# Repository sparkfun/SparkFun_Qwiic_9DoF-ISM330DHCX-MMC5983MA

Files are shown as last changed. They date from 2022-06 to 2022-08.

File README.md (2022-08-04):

SparkFun Qwiic 9DoF ISM330DHCX, MMC5983MA
========================================

SparkFun_Qwiic_9DoF-ISM330DHCX-MMC5983MA (https://www.sparkfun.com/products/19895)

[*SparkFun_Qwiic_9DoF-ISM330DHCX-MMC5983MA (19895)*](https://www.sparkfun.com/products/19895)

The SparkFun 9DoF IMU Breakout - ISM330DHCX, MMC5983MA (Qwiic) combines the high-performance ISM330DHCX 3D digital accelerometer and gyroscope from STMicroelectronics with the highly sensitive triple-axis magnetometer by MEMSIC to give you an ultra powerful, easy to use, Qwiic enabled breakout board. 

With a full scale acceleration range of ±2/±4/±8/±16 g and a wide angular rate range of ±125/±250/±500/±1000/±2000/±4000 dps, as well as an unmatched set of embedded features (Machine Learning Core, programmable FSM, FIFO, sensor hub, event decoding and interrupts), the ISM330DHCX delivers high performance at very low power. Add to that the MMC5983MA, which can measure magnetic fields within the full scale range of &#177;8 Gauss (G), with 0.25mG/0.0625mG per LSB resolution at 16bits/18bits operation mode and 0.4 mG total RMS noise level and you've got 9 Degrees of Freedom on one tiny little breakout board. 

Utilizing our handy Qwiic system, no soldering is required to connect it to the rest of your system. However, we still have broken out 0.1"-spaced pins in case you prefer to use a breadboard.  
  
Repository Contents
-------------------

* **/Documentation** - Data sheets, additional product information
* **/Hardware** - Eagle design files (.brd, .sch)
* **/Production** - Production panel files (.brd)

Documentation
--------------

* **[6DoF ISM330DHCX Library](https://github.com/sparkfun/SparkFun_6DoF_ISM330DHCX_Arduino_Library)** - Arduino library for the SparkFun Qwiic 6DoF ISM330DHCX.
* **[MMC5983MA Magnetometer Library](https://github.com/sparkfun/SparkFun_MMC5983MA_Magnetometer_Arduino_Library)** - Arduino library for the SparkFun Qwiic MMC5983MA Magnetometer.
* **[Hookup Guide](https://learn.sparkfun.com/tutorials/2616)** - Basic hookup guide for the SparkFun Qwiic 9DoF-ISM330DHCX-MMC5983MA.

License Information
-------------------

This product is _**open source**_! 

Please review the LICENSE.md file for license information. 

If you have any questions or concerns on licensing, please contact technical support on our [SparkFun forums](https://forum.sparkfun.com/viewforum.php?f=152).

Distributed as-is; no warranty is given.

- Your friends at SparkFun.

_<COLLABORATION CREDIT>_

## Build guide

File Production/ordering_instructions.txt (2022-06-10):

panel size, 169x117mm
PCB thickness, 1.6mm
number of layers, 2
soldermask color, Red
silkscreen color, White
oz copper, 1oz
finish, HASL lead free
stencils, top
pcs per panel, 24
min trace width, 0.2032mm / 0.0080in
min drill size, 0.3048mm / 0.0120in

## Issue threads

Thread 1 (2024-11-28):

Yaw pitch roll

ujwalsahu123, 2024-11-28:
Can you please give code for getting - yaw pitch roll .
Also can you explain or give steps how to get accurate RPY values . (Like - caliberation , sensor fusion , ...etc )

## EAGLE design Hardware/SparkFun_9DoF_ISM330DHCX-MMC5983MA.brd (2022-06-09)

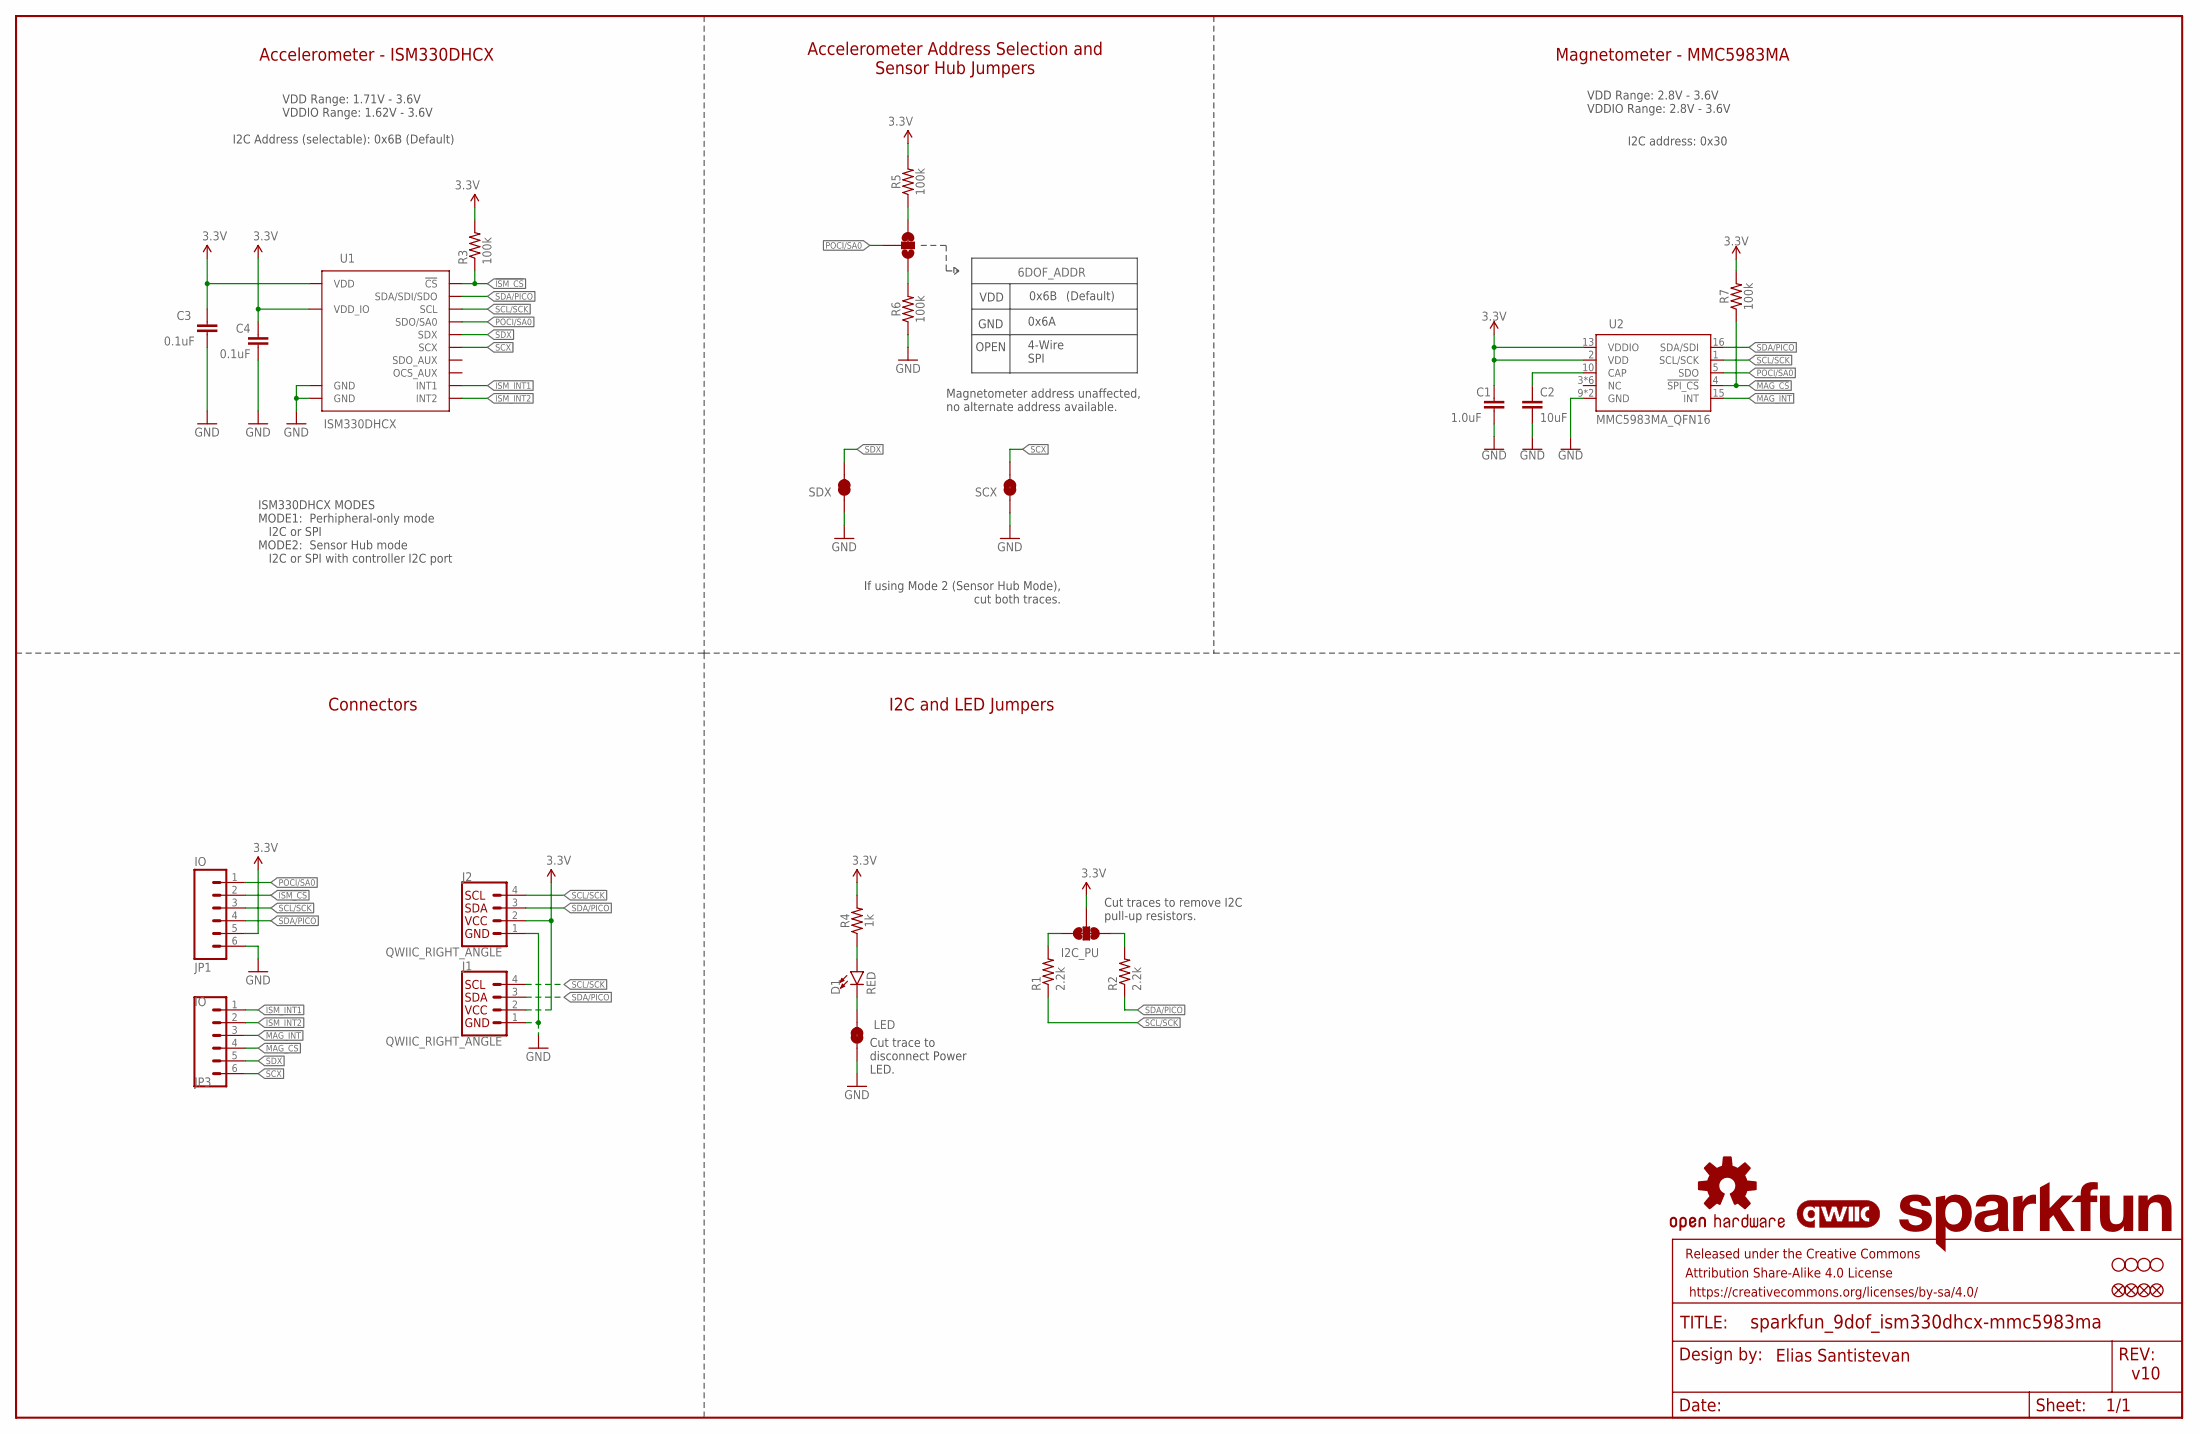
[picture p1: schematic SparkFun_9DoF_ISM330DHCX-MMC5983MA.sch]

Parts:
6DOF_ADDR: JUMPER-SMT_3_1-NC_TRACE_SILK; SMT-JUMPER_3_1-NC_TRACE_SILK
C1: 1.0uF; 0603
C2: 10uF; 0603
C3, C4: 0.1uF; 0603
D1: RED; LED-0603
FD1, FD2: FIDUCIALUFIDUCIAL; FIDUCIAL-MICRO
FID1, FID2: FIDUCIALUFIDUCIAL; FIDUCIAL-MICRO
FRAME2: FRAME-LEDGER; CREATIVE_COMMONS
I2C_PU: S_MODE; SMT-JUMPER_3_2-NC_TRACE_SILK
J1, J2: QWIIC_RIGHT_ANGLE; JST04_1MM_RA
JP1, JP3: IO; 1X06_NO_SILK
LED: JUMPER-SMT_2_NC_TRACE_SILK; SMT-JUMPER_2_NC_TRACE_SILK
LOGO1: QWIIC_LOGO_4MM; QWIIC_4MM
LOGO2: OSHW-LOGOMINI; OSHW-LOGO-MINI
LOGO3: SFE_LOGO_NAME.1_INCH; SFE_LOGO_NAME_.1
R1, R2: 2.2k; 0603
R3, R5, R6, R7: 100k; 0603
R4: 1k; 0603
SCX: JUMPER-SMT_2_NC_TRACE_SILK; SMT-JUMPER_2_NC_TRACE_SILK
SDX: JUMPER-SMT_2_NC_TRACE_SILK; SMT-JUMPER_2_NC_TRACE_SILK
STANDOFF1, STANDOFF2, STANDOFF3, STANDOFF4: STAND-OFFTIGHT; STAND-OFF-TIGHT
U1: ISM330DHCX; LGA-14L
U2: MMC5983MA_QFN16; LGA-16-3X3MM-4X4PINS

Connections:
3.3V: C1.1, C3.1, C4.1, I2C_PU.2, J1.2, J2.2, JP1.5, R3.2, R4.2, R5.2, R7.2, U1.P5 (VDD_IO), U1.P8 (VDD), U2.2 (VDD), U2.13 (VDDIO)
!ISM_CS!: JP1.2, R3.1, U1.P12 (!CS!)
!MAG_CS!: JP3.4, R7.1, U2.4 (!SPI_CS!)
CAP: C2.1, U2.10 (CAP)
GND: C1.2, C2.2, C3.2, C4.2, J1.1, J2.1, JP1.6, LED.1, R6.1, SCX.1, SDX.1, U1.P6 (GND), U1.P7 (GND), U2.9 (GND), U2.11 (GND)
ISM_INT1: JP3.1, U1.P4 (INT1)
ISM_INT2: JP3.2, U1.P9 (INT2)
MAG_INT: JP3.3, U2.15 (INT)
unnamed: 6DOF_ADDR.3, R5.1
unnamed: D1.A, R4.1
unnamed: D1.C, LED.2
unnamed: I2C_PU.1, R1.2
unnamed: I2C_PU.3, R2.2
unnamed: 6DOF_ADDR.1, R6.2
POCI/SA0: 6DOF_ADDR.2, JP1.1, U1.P1 (SDO/SA0), U2.5 (SDO)
SCL/SCK: J1.4, J2.4, JP1.3, R1.1, U1.P13 (SCL), U2.1 (SCL/SCK)
SCX: JP3.6, SCX.2, U1.P3 (SCX)
SDA/PICO: J1.3, J2.3, JP1.4, R2.1, U1.P14 (SDA/SDI/SDO), U2.16 (SDA/SDI)
SDX: JP3.5, SDX.2, U1.P2 (SDX)

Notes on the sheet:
Accelerometer - ISM330DHCX
Cut traces to remove I2C pull-up resistors.
VDD Range: 1.71V - 3.6V VDDIO Range: 1.62V - 3.6V
v10
Cut trace to disconnect Power LED.
Connectors
VDD
GND
OPEN
0x6B
0x6A
4-Wire SPI
Elias Santistevan
VDD Range: 2.8V - 3.6V VDDIO Range: 2.8V - 3.6V
Magnetometer - MMC5983MA
Accelerometer Address Selection and Sensor Hub Jumpers
I2C and LED Jumpers
I2C address: 0x30
(Default)
I2C Address (selectable): 0x6B (Default)
ISM330DHCX MODES MODE1: Perhipheral-only mode I2C or SPI MODE2: Sensor Hub mode I2C or SPI with controller I2C port
If using Mode 2 (Sensor Hub Mode), cut both traces.
Magnetometer address unaffected, no alternate address available.

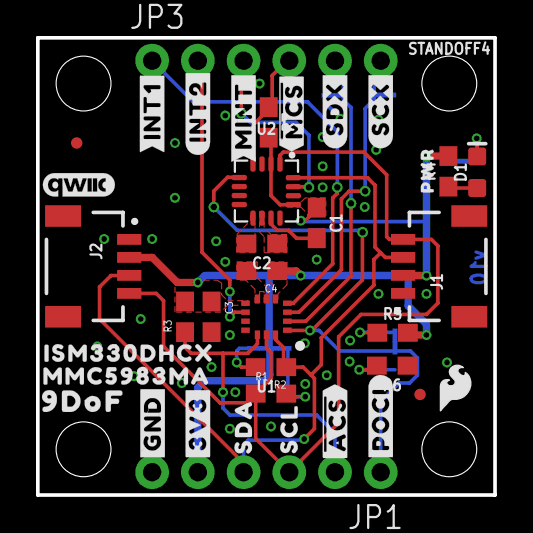
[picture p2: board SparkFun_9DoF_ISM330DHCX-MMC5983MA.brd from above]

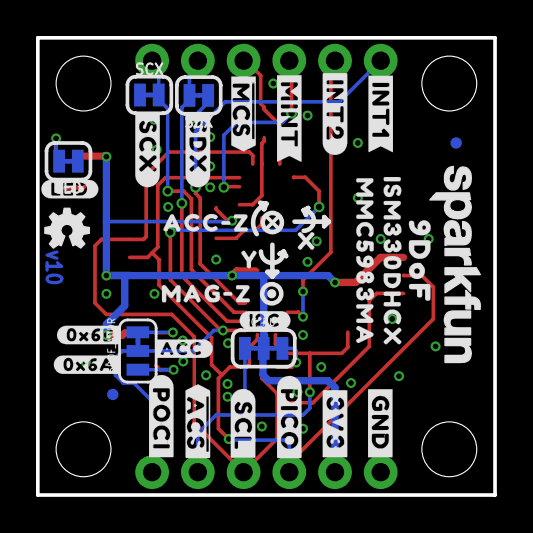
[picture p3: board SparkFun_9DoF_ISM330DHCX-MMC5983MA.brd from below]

Board: 2 copper layers, 25.4 x 25.4 mm, 76 parts (33 on the bottom side), 19 nets.

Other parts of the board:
U$1, U$15: #3V3#1
U$2, U$17: #GND#0
U$3, U$7: ISM330DHCX331
U$4: SDA14
U$5: SCL13
U$6: #POCI#11
U$8: #INT1#0
U$9: #INT2#3
U$10: #INT1#2
U$11: #INT2#2
U$12: #MINT#4
U$13: ACC#Z5985
U$14: MAG#Z5984
U$16: #LED#11
U$18: #POCI#12
U$19: ##MCS##5
U$20: #SDX#7
U$21, U$32: MMC5983MA24
U$22: #SCL#5
U$23: #SCX#8
U$24, U$30: 9DOF24
U$25: #I2C#11
U$26: #PICO#13
U$27: ##ACS##6
U$28: PWR8
U$29: SFE_LOGO_FLAME_.1
U$31: #MINT#5
U$33: #0X6A#15
U$34: ##MCS##7
U$35: #SDX#9
U$36: #SCX#11
U$37: X2114
U$38: Y2115
U$39: ##ACS##8
U$40: #0X6B#15
U$41: #ACC#17

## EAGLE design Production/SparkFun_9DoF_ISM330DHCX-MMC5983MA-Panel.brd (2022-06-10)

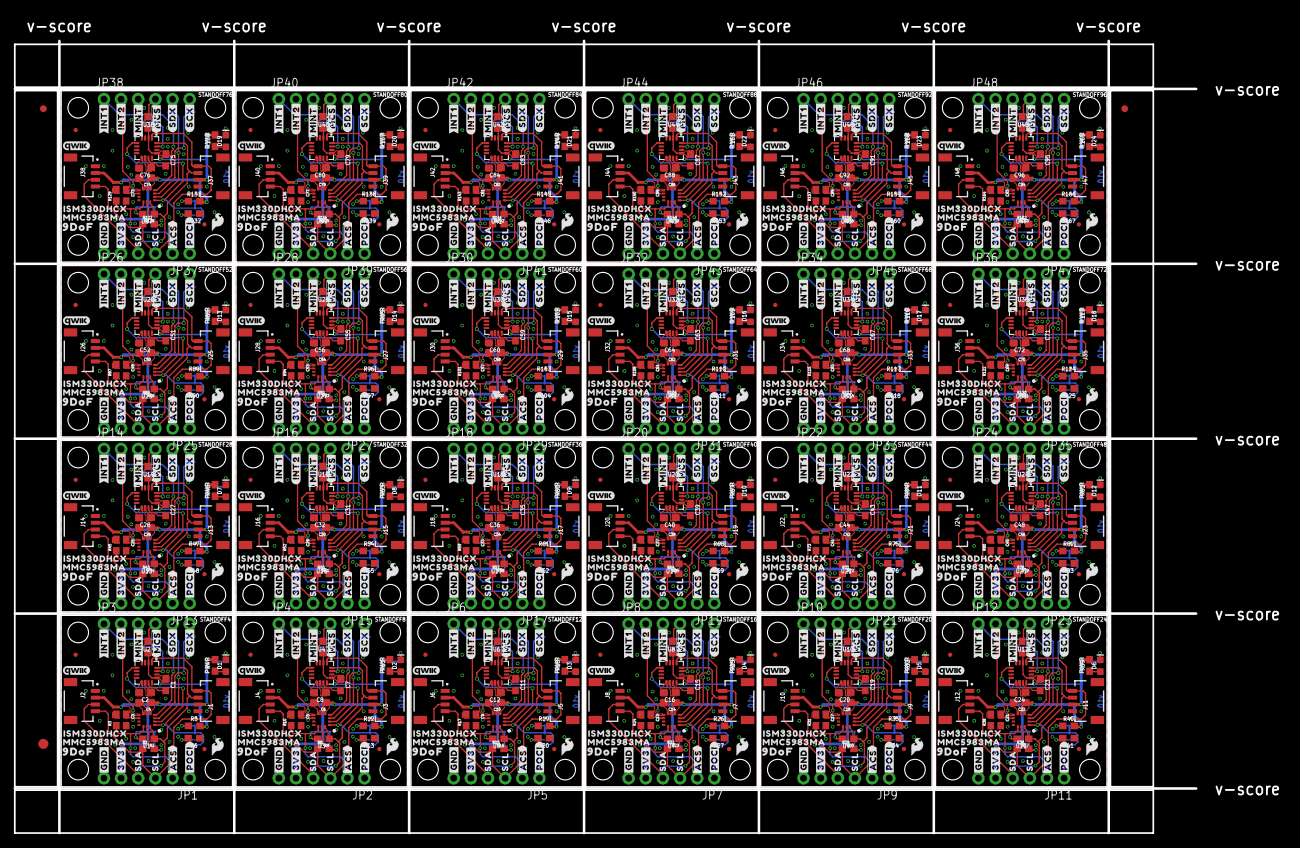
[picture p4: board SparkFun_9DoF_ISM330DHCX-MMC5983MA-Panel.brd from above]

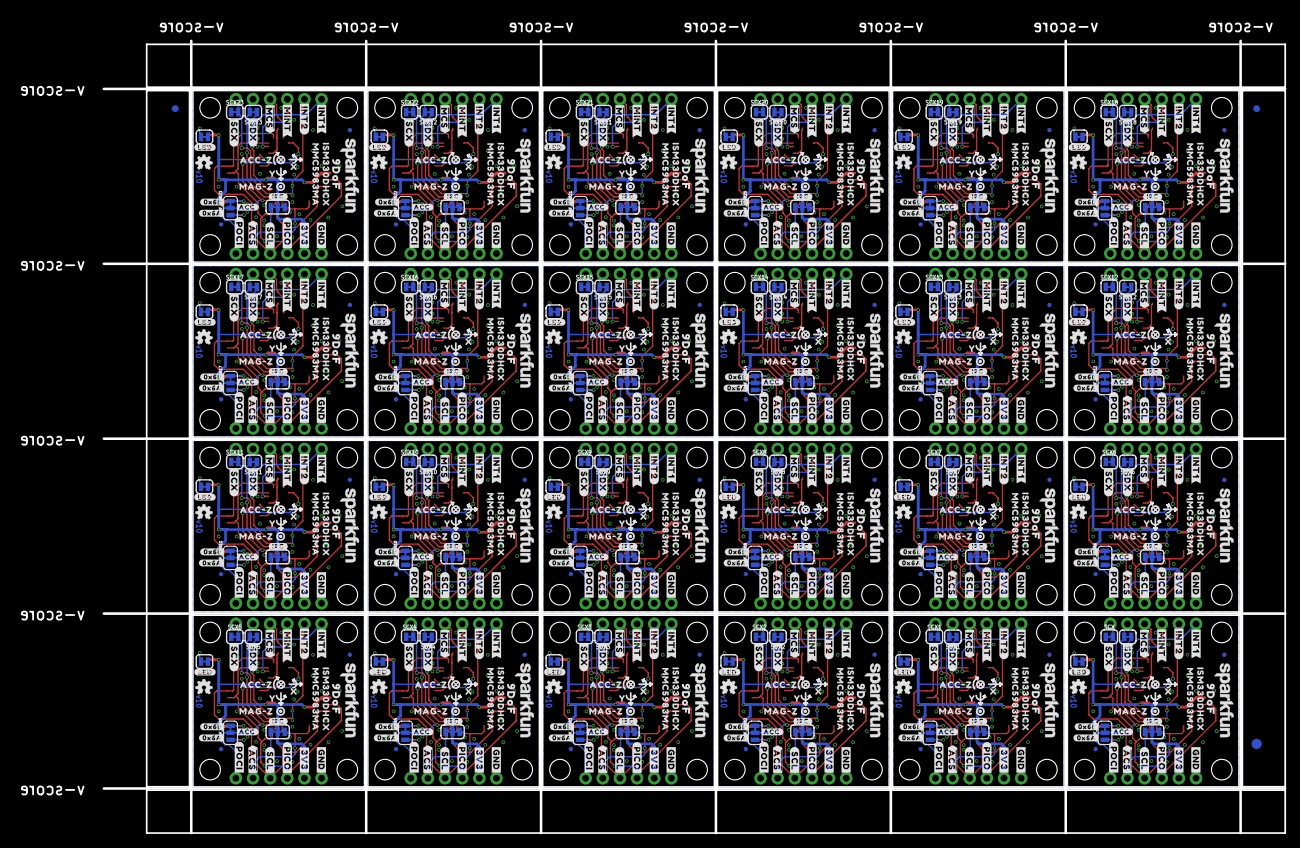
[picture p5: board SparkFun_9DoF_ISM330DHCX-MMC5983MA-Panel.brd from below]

Board: 2 copper layers, 175.0 x 117.3 mm, 1806 parts (795 on the bottom side), 456 nets.

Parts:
6DOF_ADDR, 6DOF_ADDR1, 6DOF_ADDR2, 6DOF_ADDR3, 6DOF_ADDR4, 6DOF_ADDR5, 6DOF_ADDR6, 6DOF_ADDR7, 6DOF_ADDR8, 6DOF_ADDR9, 6DOF_ADDR10, 6DOF_ADDR11, 6DOF_ADDR12, 6DOF_ADDR13, 6DOF_ADDR14, 6DOF_ADDR15, 6DOF_ADDR16, 6DOF_ADDR17, 6DOF_ADDR18, 6DOF_ADDR19, 6DOF_ADDR20, 6DOF_ADDR21, 6DOF_ADDR22, 6DOF_ADDR23: JUMPER-SMT_3_1-NC_TRACE_SILK; SMT-JUMPER_3_1-NC_TRACE_SILK
C1, C7, C11, C15, C19, C23, C27, C31, C35, C39, C43, C47, C51, C55, C59, C63, C67, C71, C75, C79, C83, C87, C91, C95: 1.0uF; 0603
C2, C8, C12, C16, C20, C24, C28, C32, C36, C40, C44, C48, C52, C56, C60, C64, C68, C72, C76, C80, C84, C88, C92, C96: 10uF; 0603
C3, C4, C5, C6, C9, C10, C13, C14, C17, C18, C21, C22, C25, C26, C29, C30, C33, C34, C37, C38, C41, C42, C45, C46, C49, C50, C53, C54, C57, C58, C61, C62, C65, C66, C69, C70, C73, C74, C77, C78, C81, C82, C85, C86, C89, C90, C93, C94: 0.1uF; 0603
D1, D2, D3, D4, D5, D6, D7, D8, D9, D10, D11, D12, D13, D14, D15, D16, D17, D18, D19, D20, D21, D22, D23, D24: RED; LED-0603
E$1, E$2, E$3, E$4: FIDUCIAL-1X2
E$5, E$6: FIDUCIAL-1.5X3
FD1, FD2, FD3, FD4, FD5, FD6, FD7, FD8, FD9, FD10, FD11, FD12, FD13, FD14, FD15, FD16, FD17, FD18, FD19, FD20, FD21, FD22, FD23, FD24, FD25, FD26, FD27, FD28, FD29, FD30, FD31, FD32, FD33, FD34, FD35, FD36, FD37, FD38, FD39, FD40, FD41, FD42, FD43, FD44, FD45, FD46, FD47, FD48: FIDUCIALUFIDUCIAL; FIDUCIAL-MICRO
FID1, FID2, FID3, FID4, FID5, FID6, FID7, FID8, FID9, FID10, FID11, FID12, FID13, FID14, FID15, FID16, FID17, FID18, FID19, FID20, FID21, FID22, FID23, FID24, FID25, FID26, FID27, FID28, FID29, FID30, FID31, FID32, FID33, FID34, FID35, FID36, FID37, FID38, FID39, FID40, FID41, FID42, FID43, FID44, FID45, FID46, FID47, FID48: FIDUCIALUFIDUCIAL; FIDUCIAL-MICRO
I2C_PU, I2C_PU1, I2C_PU2, I2C_PU3, I2C_PU4, I2C_PU5, I2C_PU6, I2C_PU7, I2C_PU8, I2C_PU9, I2C_PU10, I2C_PU11, I2C_PU12, I2C_PU13, I2C_PU14, I2C_PU15, I2C_PU16, I2C_PU17, I2C_PU18, I2C_PU19, I2C_PU20, I2C_PU21, I2C_PU22, I2C_PU23: S_MODE; SMT-JUMPER_3_2-NC_TRACE_SILK
J1, J2, J3, J4, J5, J6, J7, J8, J9, J10, J11, J12, J13, J14, J15, J16, J17, J18, J19, J20, J21, J22, J23, J24, J25, J26, J27, J28, J29, J30, J31, J32, J33, J34, J35, J36, J37, J38, J39, J40, J41, J42, J43, J44, J45, J46, J47, J48: QWIIC_RIGHT_ANGLE; JST04_1MM_RA
JP1, JP2, JP3, JP4, JP5, JP6, JP7, JP8, JP9, JP10, JP11, JP12, JP13, JP14, JP15, JP16, JP17, JP18, JP19, JP20, JP21, JP22, JP23, JP24, JP25, JP26, JP27, JP28, JP29, JP30, JP31, JP32, JP33, JP34, JP35, JP36, JP37, JP38, JP39, JP40, JP41, JP42, JP43, JP44, JP45, JP46, JP47, JP48: IO; 1X06_NO_SILK
LED, LED1, LED2, LED3, LED4, LED5, LED6, LED7, LED8, LED9, LED10, LED11, LED12, LED13, LED14, LED15, LED16, LED17, LED18, LED19, LED20, LED21, LED22, LED23: JUMPER-SMT_2_NC_TRACE_SILK; SMT-JUMPER_2_NC_TRACE_SILK
LOGO1, LOGO6, LOGO9, LOGO12, LOGO15, LOGO18, LOGO21, LOGO24, LOGO27, LOGO30, LOGO33, LOGO36, LOGO39, LOGO42, LOGO45, LOGO48, LOGO51, LOGO54, LOGO57, LOGO60, LOGO63, LOGO66, LOGO69, LOGO72: QWIIC_LOGO_4MM; QWIIC_4MM
LOGO2, LOGO4, LOGO7, LOGO10, LOGO13, LOGO16, LOGO19, LOGO22, LOGO25, LOGO28, LOGO31, LOGO34, LOGO37, LOGO40, LOGO43, LOGO46, LOGO49, LOGO52, LOGO55, LOGO58, LOGO61, LOGO64, LOGO67, LOGO70: OSHW-LOGOMINI; OSHW-LOGO-MINI
LOGO3, LOGO5, LOGO8, LOGO11, LOGO14, LOGO17, LOGO20, LOGO23, LOGO26, LOGO29, LOGO32, LOGO35, LOGO38, LOGO41, LOGO44, LOGO47, LOGO50, LOGO53, LOGO56, LOGO59, LOGO62, LOGO65, LOGO68, LOGO71: SFE_LOGO_NAME.1_INCH; SFE_LOGO_NAME_.1
R1, R2, R8, R9, R15, R16, R22, R23, R29, R30, R36, R37, R43, R44, R50, R51, R57, R58, R64, R65, R71, R72, R78, R79, R85, R86, R92, R93, R99, R100, R106, R107, R113, R114, R120, R121, R127, R128, R134, R135, R141, R142, R148, R149, R155, R156, R162, R163: 2.2k; 0603
R3, R5, R6, R7, R10, R12, R13, R14, R17, R19, R20, R21, R24, R26, R27, R28, R31, R33, R34, R35, R38, R40, R41, R42, R45, R47, R48, R49, R52, R54, R55, R56, R59, R61, R62, R63, R66, R68, R69, R70, R73, R75, R76, R77, R80, R82, R83, R84, R87, R89, R90, R91, R94, R96, R97, R98, R101, R103, R104, R105, R108, R110, R111, R112, R115, R117, R118, R119, R122, R124, R125, R126, R129, R131, R132, R133, R136, R138, R139, R140, R143, R145, R146, R147, R150, R152, R153, R154, R157, R159, R160, R161, R164, R166, R167, R168: 100k; 0603
R4, R11, R18, R25, R32, R39, R46, R53, R60, R67, R74, R81, R88, R95, R102, R109, R116, R123, R130, R137, R144, R151, R158, R165: 1k; 0603
SCX, SCX1, SCX2, SCX3, SCX4, SCX5, SCX6, SCX7, SCX8, SCX9, SCX10, SCX11, SCX12, SCX13, SCX14, SCX15, SCX16, SCX17, SCX18, SCX19, SCX20, SCX21, SCX22, SCX23: JUMPER-SMT_2_NC_TRACE_SILK; SMT-JUMPER_2_NC_TRACE_SILK
SDX, SDX1, SDX2, SDX3, SDX4, SDX5, SDX6, SDX7, SDX8, SDX9, SDX10, SDX11, SDX12, SDX13, SDX14, SDX15, SDX16, SDX17, SDX18, SDX19, SDX20, SDX21, SDX22, SDX23: JUMPER-SMT_2_NC_TRACE_SILK; SMT-JUMPER_2_NC_TRACE_SILK
STANDOFF1, STANDOFF2, STANDOFF3, STANDOFF4, STANDOFF5, STANDOFF6, STANDOFF7, STANDOFF8, STANDOFF9, STANDOFF10, STANDOFF11, STANDOFF12, STANDOFF13, STANDOFF14, STANDOFF15, STANDOFF16, STANDOFF17, STANDOFF18, STANDOFF19, STANDOFF20, STANDOFF21, STANDOFF22, STANDOFF23, STANDOFF24, STANDOFF25, STANDOFF26, STANDOFF27, STANDOFF28, STANDOFF29, STANDOFF30, STANDOFF31, STANDOFF32, STANDOFF33, STANDOFF34, STANDOFF35, STANDOFF36, STANDOFF37, STANDOFF38, STANDOFF39, STANDOFF40, STANDOFF41, STANDOFF42, STANDOFF43, STANDOFF44, STANDOFF45, STANDOFF46, STANDOFF47, STANDOFF48, STANDOFF49, STANDOFF50, STANDOFF51, STANDOFF52, STANDOFF53, STANDOFF54, STANDOFF55, STANDOFF56, STANDOFF57, STANDOFF58, STANDOFF59, STANDOFF60, STANDOFF61, STANDOFF62, STANDOFF63, STANDOFF64, STANDOFF65, STANDOFF66, STANDOFF67, STANDOFF68, STANDOFF69, STANDOFF70, STANDOFF71, STANDOFF72, STANDOFF73, STANDOFF74, STANDOFF75, STANDOFF76, STANDOFF77, STANDOFF78, STANDOFF79, STANDOFF80, STANDOFF81, STANDOFF82, STANDOFF83, STANDOFF84, STANDOFF85, STANDOFF86, STANDOFF87, STANDOFF88, STANDOFF89, STANDOFF90, STANDOFF91, STANDOFF92, STANDOFF93, STANDOFF94, STANDOFF95, STANDOFF96: STAND-OFFTIGHT; STAND-OFF-TIGHT
U1, U3, U5, U7, U9, U11, U13, U15, U17, U19, U21, U23, U25, U27, U29, U31, U33, U35, U37, U39, U41, U43, U45, U47: ISM330DHCX; LGA-14L
U2, U4, U6, U8, U10, U12, U14, U16, U18, U20, U22, U24, U26, U28, U30, U32, U34, U36, U38, U40, U42, U44, U46, U48: MMC5983MA_QFN16; LGA-16-3X3MM-4X4PINS
U$1, U$15, U$42, U$44, U$83, U$85, U$124, U$126, U$165, U$167, U$206, U$208, U$247, U$249, U$288, U$290, U$329, U$331, U$370, U$372, U$411, U$413, U$452, U$454, U$493, U$495, U$534, U$536, U$575, U$577, U$616, U$618, U$657, U$659, U$698, U$700, U$739, U$741, U$780, U$782, U$821, U$823, U$862, U$864, U$903, U$905, U$944, U$946: #3V3#1
U$2, U$17, U$43, U$45, U$84, U$86, U$125, U$127, U$166, U$168, U$207, U$209, U$248, U$250, U$289, U$291, U$330, U$332, U$371, U$373, U$412, U$414, U$453, U$455, U$494, U$496, U$535, U$537, U$576, U$578, U$617, U$619, U$658, U$660, U$699, U$701, U$740, U$742, U$781, U$783, U$822, U$824, U$863, U$865, U$904, U$906, U$945, U$947: #GND#0
U$3, U$7, U$64, U$65, U$105, U$106, U$146, U$147, U$187, U$188, U$228, U$229, U$269, U$270, U$310, U$311, U$351, U$352, U$392, U$393, U$433, U$434, U$474, U$475, U$515, U$516, U$556, U$557, U$597, U$598, U$638, U$639, U$679, U$680, U$720, U$721, U$761, U$762, U$802, U$803, U$843, U$844, U$884, U$885, U$925, U$926, U$966, U$967: ISM330DHCX331
U$4, U$78, U$119, U$160, U$201, U$242, U$283, U$324, U$365, U$406, U$447, U$488, U$529, U$570, U$611, U$652, U$693, U$734, U$775, U$816, U$857, U$898, U$939, U$980: SDA14
U$5, U$79, U$120, U$161, U$202, U$243, U$284, U$325, U$366, U$407, U$448, U$489, U$530, U$571, U$612, U$653, U$694, U$735, U$776, U$817, U$858, U$899, U$940, U$981: SCL13
U$6, U$52, U$93, U$134, U$175, U$216, U$257, U$298, U$339, U$380, U$421, U$462, U$503, U$544, U$585, U$626, U$667, U$708, U$749, U$790, U$831, U$872, U$913, U$954: #POCI#11
U$8, U$66, U$107, U$148, U$189, U$230, U$271, U$312, U$353, U$394, U$435, U$476, U$517, U$558, U$599, U$640, U$681, U$722, U$763, U$804, U$845, U$886, U$927, U$968: #INT1#0
U$9, U$74, U$115, U$156, U$197, U$238, U$279, U$320, U$361, U$402, U$443, U$484, U$525, U$566, U$607, U$648, U$689, U$730, U$771, U$812, U$853, U$894, U$935, U$976: #INT2#3
U$10, U$67, U$108, U$149, U$190, U$231, U$272, U$313, U$354, U$395, U$436, U$477, U$518, U$559, U$600, U$641, U$682, U$723, U$764, U$805, U$846, U$887, U$928, U$969: #INT1#2
U$11, U$68, U$109, U$150, U$191, U$232, U$273, U$314, U$355, U$396, U$437, U$478, U$519, U$560, U$601, U$642, U$683, U$724, U$765, U$806, U$847, U$888, U$929, U$970: #INT2#2
U$12, U$69, U$110, U$151, U$192, U$233, U$274, U$315, U$356, U$397, U$438, U$479, U$520, U$561, U$602, U$643, U$684, U$725, U$766, U$807, U$848, U$889, U$930, U$971: #MINT#4
U$13, U$62, U$103, U$144, U$185, U$226, U$267, U$308, U$349, U$390, U$431, U$472, U$513, U$554, U$595, U$636, U$677, U$718, U$759, U$800, U$841, U$882, U$923, U$964: ACC#Z5985
U$14, U$63, U$104, U$145, U$186, U$227, U$268, U$309, U$350, U$391, U$432, U$473, U$514, U$555, U$596, U$637, U$678, U$719, U$760, U$801, U$842, U$883, U$924, U$965: MAG#Z5984
U$16, U$47, U$88, U$129, U$170, U$211, U$252, U$293, U$334, U$375, U$416, U$457, U$498, U$539, U$580, U$621, U$662, U$703, U$744, U$785, U$826, U$867, U$908, U$949: #LED#11
U$18, U$53, U$94, U$135, U$176, U$217, U$258, U$299, U$340, U$381, U$422, U$463, U$504, U$545, U$586, U$627, U$668, U$709, U$750, U$791, U$832, U$873, U$914, U$955: #POCI#12
U$19, U$70, U$111, U$152, U$193, U$234, U$275, U$316, U$357, U$398, U$439, U$480, U$521, U$562, U$603, U$644, U$685, U$726, U$767, U$808, U$849, U$890, U$931, U$972: ##MCS##5
U$20, U$71, U$112, U$153, U$194, U$235, U$276, U$317, U$358, U$399, U$440, U$481, U$522, U$563, U$604, U$645, U$686, U$727, U$768, U$809, U$850, U$891, U$932, U$973: #SDX#7
U$21, U$32, U$56, U$59, U$97, U$100, U$138, U$141, U$179, U$182, U$220, U$223, U$261, U$264, U$302, U$305, U$343, U$346, U$384, U$387, U$425, U$428, U$466, U$469, U$507, U$510, U$548, U$551, U$589, U$592, U$630, U$633, U$671, U$674, U$712, U$715, U$753, U$756, U$794, U$797, U$835, U$838, U$876, U$879, U$917, U$920, U$958, U$961: MMC5983MA24
U$22, U$46, U$87, U$128, U$169, U$210, U$251, U$292, U$333, U$374, U$415, U$456, U$497, U$538, U$579, U$620, U$661, U$702, U$743, U$784, U$825, U$866, U$907, U$948: #SCL#5
U$23, U$72, U$113, U$154, U$195, U$236, U$277, U$318, U$359, U$400, U$441, U$482, U$523, U$564, U$605, U$646, U$687, U$728, U$769, U$810, U$851, U$892, U$933, U$974: #SCX#8
U$24, U$30, U$57, U$58, U$98, U$99, U$139, U$140, U$180, U$181, U$221, U$222, U$262, U$263, U$303, U$304, U$344, U$345, U$385, U$386, U$426, U$427, U$467, U$468, U$508, U$509, U$549, U$550, U$590, U$591, U$631, U$632, U$672, U$673, U$713, U$714, U$754, U$755, U$795, U$796, U$836, U$837, U$877, U$878, U$918, U$919, U$959, U$960: 9DOF24
U$25, U$48, U$89, U$130, U$171, U$212, U$253, U$294, U$335, U$376, U$417, U$458, U$499, U$540, U$581, U$622, U$663, U$704, U$745, U$786, U$827, U$868, U$909, U$950: #I2C#11
U$26, U$51, U$92, U$133, U$174, U$215, U$256, U$297, U$338, U$379, U$420, U$461, U$502, U$543, U$584, U$625, U$666, U$707, U$748, U$789, U$830, U$871, U$912, U$953: #PICO#13
U$27, U$73, U$114, U$155, U$196, U$237, U$278, U$319, U$360, U$401, U$442, U$483, U$524, U$565, U$606, U$647, U$688, U$729, U$770, U$811, U$852, U$893, U$934, U$975: ##ACS##6
U$28, U$49, U$90, U$131, U$172, U$213, U$254, U$295, U$336, U$377, U$418, U$459, U$500, U$541, U$582, U$623, U$664, U$705, U$746, U$787, U$828, U$869, U$910, U$951: PWR8
U$29, U$50, U$91, U$132, U$173, U$214, U$255, U$296, U$337, U$378, U$419, U$460, U$501, U$542, U$583, U$624, U$665, U$706, U$747, U$788, U$829, U$870, U$911, U$952: SFE_LOGO_FLAME_.1
U$31, U$80, U$121, U$162, U$203, U$244, U$285, U$326, U$367, U$408, U$449, U$490, U$531, U$572, U$613, U$654, U$695, U$736, U$777, U$818, U$859, U$900, U$941, U$982: #MINT#5
U$33, U$60, U$101, U$142, U$183, U$224, U$265, U$306, U$347, U$388, U$429, U$470, U$511, U$552, U$593, U$634, U$675, U$716, U$757, U$798, U$839, U$880, U$921, U$962: #0X6A#15
U$34, U$81, U$122, U$163, U$204, U$245, U$286, U$327, U$368, U$409, U$450, U$491, U$532, U$573, U$614, U$655, U$696, U$737, U$778, U$819, U$860, U$901, U$942, U$983: ##MCS##7
U$35, U$75, U$116, U$157, U$198, U$239, U$280, U$321, U$362, U$403, U$444, U$485, U$526, U$567, U$608, U$649, U$690, U$731, U$772, U$813, U$854, U$895, U$936, U$977: #SDX#9
U$36, U$76, U$117, U$158, U$199, U$240, U$281, U$322, U$363, U$404, U$445, U$486, U$527, U$568, U$609, U$650, U$691, U$732, U$773, U$814, U$855, U$896, U$937, U$978: #SCX#11
U$37, U$54, U$95, U$136, U$177, U$218, U$259, U$300, U$341, U$382, U$423, U$464, U$505, U$546, U$587, U$628, U$669, U$710, U$751, U$792, U$833, U$874, U$915, U$956: X2114
U$38, U$55, U$96, U$137, U$178, U$219, U$260, U$301, U$342, U$383, U$424, U$465, U$506, U$547, U$588, U$629, U$670, U$711, U$752, U$793, U$834, U$875, U$916, U$957: Y2115
U$39, U$77, U$118, U$159, U$200, U$241, U$282, U$323, U$364, U$405, U$446, U$487, U$528, U$569, U$610, U$651, U$692, U$733, U$774, U$815, U$856, U$897, U$938, U$979: ##ACS##8
U$40, U$61, U$102, U$143, U$184, U$225, U$266, U$307, U$348, U$389, U$430, U$471, U$512, U$553, U$594, U$635, U$676, U$717, U$758, U$799, U$840, U$881, U$922, U$963: #0X6B#15
U$41, U$82, U$123, U$164, U$205, U$246, U$287, U$328, U$369, U$410, U$451, U$492, U$533, U$574, U$615, U$656, U$697, U$738, U$779, U$820, U$861, U$902, U$943, U$984: #ACC#17

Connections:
3.3V: C1.1, C3.1, C4.1, I2C_PU.2, J1.2, J2.2, JP1.5, R3.2, R4.2, R5.2, R7.2, U1.P5, U1.P8, U2.2, U2.13
3.3V1: C5.1, C6.1, C7.1, I2C_PU1.2, J3.2, J4.2, JP2.5, R10.2, R11.2, R12.2, R14.2, U3.P5, U3.P8, U4.2, U4.13
3.3V2: C9.1, C10.1, C11.1, I2C_PU2.2, J5.2, J6.2, JP5.5, R17.2, R18.2, R19.2, R21.2, U5.P5, U5.P8, U6.2, U6.13
3.3V3: C13.1, C14.1, C15.1, I2C_PU3.2, J7.2, J8.2, JP7.5, R24.2, R25.2, R26.2, R28.2, U7.P5, U7.P8, U8.2, U8.13
3.3V4: C17.1, C18.1, C19.1, I2C_PU4.2, J9.2, J10.2, JP9.5, R31.2, R32.2, R33.2, R35.2, U9.P5, U9.P8, U10.2, U10.13
3.3V5: C21.1, C22.1, C23.1, I2C_PU5.2, J11.2, J12.2, JP11.5, R38.2, R39.2, R40.2, R42.2, U11.P5, U11.P8, U12.2, U12.13
3.3V6: C25.1, C26.1, C27.1, I2C_PU6.2, J13.2, J14.2, JP13.5, R45.2, R46.2, R47.2, R49.2, U13.P5, U13.P8, U14.2, U14.13
3.3V7: C29.1, C30.1, C31.1, I2C_PU7.2, J15.2, J16.2, JP15.5, R52.2, R53.2, R54.2, R56.2, U15.P5, U15.P8, U16.2, U16.13
3.3V8: C33.1, C34.1, C35.1, I2C_PU8.2, J17.2, J18.2, JP17.5, R59.2, R60.2, R61.2, R63.2, U17.P5, U17.P8, U18.2, U18.13
3.3V9: C37.1, C38.1, C39.1, I2C_PU9.2, J19.2, J20.2, JP19.5, R66.2, R67.2, R68.2, R70.2, U19.P5, U19.P8, U20.2, U20.13
3.3V10: C41.1, C42.1, C43.1, I2C_PU10.2, J21.2, J22.2, JP21.5, R73.2, R74.2, R75.2, R77.2, U21.P5, U21.P8, U22.2, U22.13
3.3V11: C45.1, C46.1, C47.1, I2C_PU11.2, J23.2, J24.2, JP23.5, R80.2, R81.2, R82.2, R84.2, U23.P5, U23.P8, U24.2, U24.13
3.3V12: C49.1, C50.1, C51.1, I2C_PU12.2, J25.2, J26.2, JP25.5, R87.2, R88.2, R89.2, R91.2, U25.P5, U25.P8, U26.2, U26.13
3.3V13: C53.1, C54.1, C55.1, I2C_PU13.2, J27.2, J28.2, JP27.5, R94.2, R95.2, R96.2, R98.2, U27.P5, U27.P8, U28.2, U28.13
3.3V14: C57.1, C58.1, C59.1, I2C_PU14.2, J29.2, J30.2, JP29.5, R101.2, R102.2, R103.2, R105.2, U29.P5, U29.P8, U30.2, U30.13
3.3V15: C61.1, C62.1, C63.1, I2C_PU15.2, J31.2, J32.2, JP31.5, R108.2, R109.2, R110.2, R112.2, U31.P5, U31.P8, U32.2, U32.13
3.3V16: C65.1, C66.1, C67.1, I2C_PU16.2, J33.2, J34.2, JP33.5, R115.2, R116.2, R117.2, R119.2, U33.P5, U33.P8, U34.2, U34.13
3.3V17: C69.1, C70.1, C71.1, I2C_PU17.2, J35.2, J36.2, JP35.5, R122.2, R123.2, R124.2, R126.2, U35.P5, U35.P8, U36.2, U36.13
3.3V18: C73.1, C74.1, C75.1, I2C_PU18.2, J37.2, J38.2, JP37.5, R129.2, R130.2, R131.2, R133.2, U37.P5, U37.P8, U38.2, U38.13
3.3V19: C77.1, C78.1, C79.1, I2C_PU19.2, J39.2, J40.2, JP39.5, R136.2, R137.2, R138.2, R140.2, U39.P5, U39.P8, U40.2, U40.13
3.3V20: C81.1, C82.1, C83.1, I2C_PU20.2, J41.2, J42.2, JP41.5, R143.2, R144.2, R145.2, R147.2, U41.P5, U41.P8, U42.2, U42.13
3.3V21: C85.1, C86.1, C87.1, I2C_PU21.2, J43.2, J44.2, JP43.5, R150.2, R151.2, R152.2, R154.2, U43.P5, U43.P8, U44.2, U44.13
3.3V22: C89.1, C90.1, C91.1, I2C_PU22.2, J45.2, J46.2, JP45.5, R157.2, R158.2, R159.2, R161.2, U45.P5, U45.P8, U46.2, U46.13
3.3V23: C93.1, C94.1, C95.1, I2C_PU23.2, J47.2, J48.2, JP47.5, R164.2, R165.2, R166.2, R168.2, U47.P5, U47.P8, U48.2, U48.13
!ISM_CS!: JP1.2, R3.1, U1.P12
!ISM_CS!1: JP2.2, R10.1, U3.P12
!ISM_CS!2: JP5.2, R17.1, U5.P12
!ISM_CS!3: JP7.2, R24.1, U7.P12
!ISM_CS!4: JP9.2, R31.1, U9.P12
!ISM_CS!5: JP11.2, R38.1, U11.P12
!ISM_CS!6: JP13.2, R45.1, U13.P12
!ISM_CS!7: JP15.2, R52.1, U15.P12
!ISM_CS!8: JP17.2, R59.1, U17.P12
!ISM_CS!9: JP19.2, R66.1, U19.P12
!ISM_CS!10: JP21.2, R73.1, U21.P12
!ISM_CS!11: JP23.2, R80.1, U23.P12
!ISM_CS!12: JP25.2, R87.1, U25.P12
!ISM_CS!13: JP27.2, R94.1, U27.P12
!ISM_CS!14: JP29.2, R101.1, U29.P12
!ISM_CS!15: JP31.2, R108.1, U31.P12
!ISM_CS!16: JP33.2, R115.1, U33.P12
!ISM_CS!17: JP35.2, R122.1, U35.P12
!ISM_CS!18: JP37.2, R129.1, U37.P12
!ISM_CS!19: JP39.2, R136.1, U39.P12
!ISM_CS!20: JP41.2, R143.1, U41.P12
!ISM_CS!21: JP43.2, R150.1, U43.P12
!ISM_CS!22: JP45.2, R157.1, U45.P12
!ISM_CS!23: JP47.2, R164.1, U47.P12
!MAG_CS!: JP3.4, R7.1, U2.4
!MAG_CS!1: JP4.4, R14.1, U4.4
!MAG_CS!2: JP6.4, R21.1, U6.4
!MAG_CS!3: JP8.4, R28.1, U8.4
!MAG_CS!4: JP10.4, R35.1, U10.4
!MAG_CS!5: JP12.4, R42.1, U12.4
!MAG_CS!6: JP14.4, R49.1, U14.4
!MAG_CS!7: JP16.4, R56.1, U16.4
!MAG_CS!8: JP18.4, R63.1, U18.4
!MAG_CS!9: JP20.4, R70.1, U20.4
!MAG_CS!10: JP22.4, R77.1, U22.4
!MAG_CS!11: JP24.4, R84.1, U24.4
!MAG_CS!12: JP26.4, R91.1, U26.4
!MAG_CS!13: JP28.4, R98.1, U28.4
!MAG_CS!14: JP30.4, R105.1, U30.4
!MAG_CS!15: JP32.4, R112.1, U32.4
!MAG_CS!16: JP34.4, R119.1, U34.4
!MAG_CS!17: JP36.4, R126.1, U36.4
!MAG_CS!18: JP38.4, R133.1, U38.4
!MAG_CS!19: JP40.4, R140.1, U40.4
!MAG_CS!20: JP42.4, R147.1, U42.4
!MAG_CS!21: JP44.4, R154.1, U44.4
!MAG_CS!22: JP46.4, R161.1, U46.4
!MAG_CS!23: JP48.4, R168.1, U48.4
CAP: C2.1, U2.10
CAP1: C8.1, U4.10
CAP2: C12.1, U6.10
CAP3: C16.1, U8.10
CAP4: C20.1, U10.10
CAP5: C24.1, U12.10
CAP6: C28.1, U14.10
CAP7: C32.1, U16.10
CAP8: C36.1, U18.10
CAP9: C40.1, U20.10
CAP10: C44.1, U22.10
CAP11: C48.1, U24.10
CAP12: C52.1, U26.10
CAP13: C56.1, U28.10
CAP14: C60.1, U30.10
CAP15: C64.1, U32.10
CAP16: C68.1, U34.10
CAP17: C72.1, U36.10
CAP18: C76.1, U38.10
CAP19: C80.1, U40.10
CAP20: C84.1, U42.10
CAP21: C88.1, U44.10
CAP22: C92.1, U46.10
CAP23: C96.1, U48.10
GND: C1.2, C2.2, C3.2, C4.2, J1.1, J2.1, JP1.6, LED.1, R6.1, SCX.1, SDX.1, U1.P6, U1.P7, U2.9, U2.11
GND1: C5.2, C6.2, C7.2, C8.2, J3.1, J4.1, JP2.6, LED1.1, R13.1, SCX1.1, SDX1.1, U3.P6, U3.P7, U4.9, U4.11
GND2: C9.2, C10.2, C11.2, C12.2, J5.1, J6.1, JP5.6, LED2.1, R20.1, SCX2.1, SDX2.1, U5.P6, U5.P7, U6.9, U6.11
GND3: C13.2, C14.2, C15.2, C16.2, J7.1, J8.1, JP7.6, LED3.1, R27.1, SCX3.1, SDX3.1, U7.P6, U7.P7, U8.9, U8.11
GND4: C17.2, C18.2, C19.2, C20.2, J9.1, J10.1, JP9.6, LED4.1, R34.1, SCX4.1, SDX4.1, U9.P6, U9.P7, U10.9, U10.11
GND5: C21.2, C22.2, C23.2, C24.2, J11.1, J12.1, JP11.6, LED5.1, R41.1, SCX5.1, SDX5.1, U11.P6, U11.P7, U12.9, U12.11
GND6: C25.2, C26.2, C27.2, C28.2, J13.1, J14.1, JP13.6, LED6.1, R48.1, SCX6.1, SDX6.1, U13.P6, U13.P7, U14.9, U14.11
GND7: C29.2, C30.2, C31.2, C32.2, J15.1, J16.1, JP15.6, LED7.1, R55.1, SCX7.1, SDX7.1, U15.P6, U15.P7, U16.9, U16.11
GND8: C33.2, C34.2, C35.2, C36.2, J17.1, J18.1, JP17.6, LED8.1, R62.1, SCX8.1, SDX8.1, U17.P6, U17.P7, U18.9, U18.11
GND9: C37.2, C38.2, C39.2, C40.2, J19.1, J20.1, JP19.6, LED9.1, R69.1, SCX9.1, SDX9.1, U19.P6, U19.P7, U20.9, U20.11
GND10: C41.2, C42.2, C43.2, C44.2, J21.1, J22.1, JP21.6, LED10.1, R76.1, SCX10.1, SDX10.1, U21.P6, U21.P7, U22.9, U22.11
GND11: C45.2, C46.2, C47.2, C48.2, J23.1, J24.1, JP23.6, LED11.1, R83.1, SCX11.1, SDX11.1, U23.P6, U23.P7, U24.9, U24.11
GND12: C49.2, C50.2, C51.2, C52.2, J25.1, J26.1, JP25.6, LED12.1, R90.1, SCX12.1, SDX12.1, U25.P6, U25.P7, U26.9, U26.11
GND13: C53.2, C54.2, C55.2, C56.2, J27.1, J28.1, JP27.6, LED13.1, R97.1, SCX13.1, SDX13.1, U27.P6, U27.P7, U28.9, U28.11
GND14: C57.2, C58.2, C59.2, C60.2, J29.1, J30.1, JP29.6, LED14.1, R104.1, SCX14.1, SDX14.1, U29.P6, U29.P7, U30.9, U30.11
GND15: C61.2, C62.2, C63.2, C64.2, J31.1, J32.1, JP31.6, LED15.1, R111.1, SCX15.1, SDX15.1, U31.P6, U31.P7, U32.9, U32.11
GND16: C65.2, C66.2, C67.2, C68.2, J33.1, J34.1, JP33.6, LED16.1, R118.1, SCX16.1, SDX16.1, U33.P6, U33.P7, U34.9, U34.11
GND17: C69.2, C70.2, C71.2, C72.2, J35.1, J36.1, JP35.6, LED17.1, R125.1, SCX17.1, SDX17.1, U35.P6, U35.P7, U36.9, U36.11
GND18: C73.2, C74.2, C75.2, C76.2, J37.1, J38.1, JP37.6, LED18.1, R132.1, SCX18.1, SDX18.1, U37.P6, U37.P7, U38.9, U38.11
GND19: C77.2, C78.2, C79.2, C80.2, J39.1, J40.1, JP39.6, LED19.1, R139.1, SCX19.1, SDX19.1, U39.P6, U39.P7, U40.9, U40.11
GND20: C81.2, C82.2, C83.2, C84.2, J41.1, J42.1, JP41.6, LED20.1, R146.1, SCX20.1, SDX20.1, U41.P6, U41.P7, U42.9, U42.11
GND21: C85.2, C86.2, C87.2, C88.2, J43.1, J44.1, JP43.6, LED21.1, R153.1, SCX21.1, SDX21.1, U43.P6, U43.P7, U44.9, U44.11
GND22: C89.2, C90.2, C91.2, C92.2, J45.1, J46.1, JP45.6, LED22.1, R160.1, SCX22.1, SDX22.1, U45.P6, U45.P7, U46.9, U46.11
GND23: C93.2, C94.2, C95.2, C96.2, J47.1, J48.1, JP47.6, LED23.1, R167.1, SCX23.1, SDX23.1, U47.P6, U47.P7, U48.9, U48.11
ISM_INT1: JP3.1, U1.P4
ISM_INT2: JP3.2, U1.P9
ISM_INT3: JP4.1, U3.P4
ISM_INT4: JP4.2, U3.P9
ISM_INT5: JP6.1, U5.P4
ISM_INT6: JP6.2, U5.P9
ISM_INT7: JP8.1, U7.P4
ISM_INT8: JP8.2, U7.P9
ISM_INT9: JP10.1, U9.P4
ISM_INT10: JP10.2, U9.P9
ISM_INT11: JP12.1, U11.P4
ISM_INT12: JP12.2, U11.P9
ISM_INT13: JP14.1, U13.P4
ISM_INT14: JP14.2, U13.P9
ISM_INT15: JP16.1, U15.P4
ISM_INT16: JP16.2, U15.P9
ISM_INT17: JP18.1, U17.P4
ISM_INT18: JP18.2, U17.P9
ISM_INT19: JP20.1, U19.P4
ISM_INT20: JP20.2, U19.P9
ISM_INT21: JP22.1, U21.P4
ISM_INT22: JP22.2, U21.P9
ISM_INT23: JP24.1, U23.P4
ISM_INT24: JP24.2, U23.P9
ISM_INT25: JP26.1, U25.P4
ISM_INT26: JP26.2, U25.P9
ISM_INT27: JP28.1, U27.P4
ISM_INT28: JP28.2, U27.P9
ISM_INT29: JP30.1, U29.P4
ISM_INT30: JP30.2, U29.P9
ISM_INT31: JP32.1, U31.P4
ISM_INT32: JP32.2, U31.P9
ISM_INT33: JP34.1, U33.P4
ISM_INT34: JP34.2, U33.P9
ISM_INT35: JP36.1, U35.P4
ISM_INT36: JP36.2, U35.P9
ISM_INT37: JP38.1, U37.P4
ISM_INT38: JP38.2, U37.P9
ISM_INT39: JP40.1, U39.P4
ISM_INT40: JP40.2, U39.P9
ISM_INT41: JP42.1, U41.P4
ISM_INT42: JP42.2, U41.P9
ISM_INT43: JP44.1, U43.P4
ISM_INT44: JP44.2, U43.P9
ISM_INT45: JP46.1, U45.P4
ISM_INT46: JP46.2, U45.P9
ISM_INT47: JP48.1, U47.P4
ISM_INT48: JP48.2, U47.P9
MAG_INT: JP3.3, U2.15
MAG_INT1: JP4.3, U4.15
MAG_INT2: JP6.3, U6.15
MAG_INT3: JP8.3, U8.15
MAG_INT4: JP10.3, U10.15
MAG_INT5: JP12.3, U12.15
MAG_INT6: JP14.3, U14.15
MAG_INT7: JP16.3, U16.15
MAG_INT8: JP18.3, U18.15
MAG_INT9: JP20.3, U20.15
MAG_INT10: JP22.3, U22.15
MAG_INT11: JP24.3, U24.15
MAG_INT12: JP26.3, U26.15
MAG_INT13: JP28.3, U28.15
MAG_INT14: JP30.3, U30.15
MAG_INT15: JP32.3, U32.15
MAG_INT16: JP34.3, U34.15
MAG_INT17: JP36.3, U36.15
MAG_INT18: JP38.3, U38.15
MAG_INT19: JP40.3, U40.15
MAG_INT20: JP42.3, U42.15
MAG_INT21: JP44.3, U44.15
MAG_INT22: JP46.3, U46.15
MAG_INT23: JP48.3, U48.15
unnamed: 6DOF_ADDR.3, R5.1
unnamed: D1.A, R4.1
unnamed: D1.C, LED.2
unnamed: I2C_PU1.1, R8.2
unnamed: I2C_PU.1, R1.2
unnamed: I2C_PU.3, R2.2
unnamed: 6DOF_ADDR.1, R6.2
unnamed: I2C_PU1.3, R9.2
unnamed: D2.A, R11.1
unnamed: D2.C, LED1.2
unnamed: 6DOF_ADDR1.3, R12.1
unnamed: 6DOF_ADDR1.1, R13.2
unnamed: I2C_PU2.1, R15.2
unnamed: I2C_PU2.3, R16.2
unnamed: D3.A, R18.1
unnamed: D3.C, LED2.2
unnamed: 6DOF_ADDR2.3, R19.1
unnamed: 6DOF_ADDR2.1, R20.2
unnamed: I2C_PU3.1, R22.2
unnamed: I2C_PU3.3, R23.2
unnamed: D4.A, R25.1
unnamed: D4.C, LED3.2
unnamed: 6DOF_ADDR3.3, R26.1
unnamed: 6DOF_ADDR3.1, R27.2
unnamed: I2C_PU4.1, R29.2
unnamed: I2C_PU4.3, R30.2
unnamed: D5.A, R32.1
unnamed: D5.C, LED4.2
unnamed: 6DOF_ADDR4.3, R33.1
unnamed: 6DOF_ADDR4.1, R34.2
unnamed: I2C_PU5.1, R36.2
unnamed: I2C_PU5.3, R37.2
unnamed: D6.A, R39.1
unnamed: D6.C, LED5.2
unnamed: 6DOF_ADDR5.3, R40.1
unnamed: 6DOF_ADDR5.1, R41.2
unnamed: I2C_PU6.1, R43.2
unnamed: I2C_PU6.3, R44.2
unnamed: D7.A, R46.1
unnamed: D7.C, LED6.2
unnamed: 6DOF_ADDR6.3, R47.1
unnamed: 6DOF_ADDR6.1, R48.2
unnamed: I2C_PU7.1, R50.2
unnamed: I2C_PU7.3, R51.2
unnamed: D8.A, R53.1
unnamed: D8.C, LED7.2
unnamed: 6DOF_ADDR7.3, R54.1
unnamed: 6DOF_ADDR7.1, R55.2
unnamed: I2C_PU8.1, R57.2
unnamed: I2C_PU8.3, R58.2
unnamed: D9.A, R60.1
unnamed: D9.C, LED8.2
unnamed: 6DOF_ADDR8.3, R61.1
unnamed: 6DOF_ADDR8.1, R62.2
unnamed: I2C_PU9.1, R64.2
unnamed: I2C_PU9.3, R65.2
unnamed: D10.A, R67.1
unnamed: D10.C, LED9.2
unnamed: 6DOF_ADDR9.3, R68.1
unnamed: 6DOF_ADDR9.1, R69.2
unnamed: I2C_PU10.1, R71.2
unnamed: I2C_PU10.3, R72.2
unnamed: D11.A, R74.1
unnamed: D11.C, LED10.2
unnamed: 6DOF_ADDR10.3, R75.1
unnamed: 6DOF_ADDR10.1, R76.2
unnamed: I2C_PU11.1, R78.2
unnamed: I2C_PU11.3, R79.2
unnamed: D12.A, R81.1
unnamed: D12.C, LED11.2
unnamed: 6DOF_ADDR11.3, R82.1
unnamed: 6DOF_ADDR11.1, R83.2
unnamed: I2C_PU12.1, R85.2
unnamed: I2C_PU12.3, R86.2
unnamed: D13.A, R88.1
unnamed: D13.C, LED12.2
unnamed: 6DOF_ADDR12.3, R89.1
unnamed: 6DOF_ADDR12.1, R90.2
unnamed: I2C_PU13.1, R92.2
unnamed: I2C_PU13.3, R93.2
unnamed: D14.A, R95.1
unnamed: D14.C, LED13.2
unnamed: 6DOF_ADDR13.3, R96.1
unnamed: 6DOF_ADDR13.1, R97.2
unnamed: I2C_PU14.1, R99.2
unnamed: I2C_PU14.3, R100.2
unnamed: D15.A, R102.1
unnamed: D15.C, LED14.2
unnamed: 6DOF_ADDR14.3, R103.1
unnamed: 6DOF_ADDR14.1, R104.2
unnamed: I2C_PU15.1, R106.2
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

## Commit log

2022-04-25 Restricts ground pour around Magnetometer, renames 6DoF I2C nets
    [SparkFun_9DoF_ISM330DHCX-MMC5983MA.brd, SparkFun_9DoF_ISM330DHCX-MMC5983MA.sch]
2022-04-26 Fixes many silk errors
    * Adds polarity marker to MMC - previous one is eaten by PTH silk
    * Adds flags to interrupt silk
    * Moves resistor to make room for SDA and SCL silk
    * Renames "MAG SDA/SCL" net to "AUX SDA/SCL"
    * Rotates version number in copper
    [SparkFun_9DoF_ISM330DHCX-MMC5983MA.brd, SparkFun_9DoF_ISM330DHCX-MMC5983MA.sch]
2022-04-26 Changes main 6DoF to new part
    [SparkFun_9DoF_ISM330DHCX-MMC5983MA.brd, SparkFun_9DoF_ISM330DHCX-MMC5983MA.sch]
2022-04-26 Renames board files to reflect 6DoF part change
    [SparkFun_9DoF_ISM330DLC-MMC5983MA.brd, SparkFun_9DoF_ISM330DLC-MMC5983MA.sch, SparkFun_9DoF_ISM330DLC-MMC5983MA_Qwiic_Micro.brd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]
2022-04-26 Updates silk on board to reflect part change
    [SparkFun_9DoF_ISM330DLC-MMC5983MA.brd]
2022-04-26 Fixes clearance issue
    [SparkFun_9DoF_ISM330DLC-MMC5983MA.brd]
2022-04-26 Updates text in schematic referencing old part
    [SparkFun_9DoF_ISM330DLC-MMC5983MA.sch]
2022-04-26 Adds gerbers
    [SparkFun_9DoF_ISM330DLC-MMC5983MA.GBL, SparkFun_9DoF_ISM330DLC-MMC5983MA.GBO, SparkFun_9DoF_ISM330DLC-MMC5983MA.GBP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]
2022-06-08 Updates routing
    [SparkFun_9DoF_ISM330DHCX-MMC5983MA.brd, SparkFun_9DoF_ISM330DHCX-MMC5983MA.sch]
2022-06-08 More updates to the routing
    [SparkFun_9DoF_ISM330DHCX-MMC5983MA.brd]
2022-06-08 Finishes routing
    [SparkFun_9DoF_ISM330DHCX-MMC5983MA.brd]
2022-06-08 Vias applied
    [SparkFun_9DoF_ISM330DHCX-MMC5983MA.brd]
2022-06-08 Adds text to schematic, adds jumpers to SDX and SCX
    [SparkFun_9DoF_ISM330DHCX-MMC5983MA.brd, SparkFun_9DoF_ISM330DHCX-MMC5983MA.sch]
2022-06-08 Adds silk
    [SparkFun_9DoF_ISM330DHCX-MMC5983MA.brd]
2022-06-08 Adds a via
    [SparkFun_9DoF_ISM330DHCX-MMC5983MA.brd]
2022-06-08 Removes old designs
    [SparkFun_9DoF_ISM330DHCX-MMC5983MA.brd, SparkFun_9DoF_ISM330DHCX-MMC5983MA.sch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]
2022-06-08 Rolls to version v02
    [SparkFun_9DoF_ISM330DHCX-MMC5983MA.brd, SparkFun_9DoF_ISM330DHCX-MMC5983MA.sch]
2022-06-09 Rotates R7 to make room for silk, nudges R2 to make room for silk
    * Fixes some DRC errors
    [SparkFun_9DoF_ISM330DHCX-MMC5983MA.brd]
2022-06-09 Nudges some vias around to avoid collisions with silk
    [SparkFun_9DoF_ISM330DHCX-MMC5983MA.brd]
2022-06-09 Rolls to v10, adds silk to accelerometer address selection jumper
    * Adds note to schematic about magnetometer address not being affected by accelerometer address selection
    * Increases size of VCC and address text
    [SparkFun_9DoF_ISM330DHCX-MMC5983MA.brd, SparkFun_9DoF_ISM330DHCX-MMC5983MA.sch]
2022-06-10 Adds production files
    [SparkFun_9DoF_ISM330DHCX-MMC5983MA-Panel.GBL, SparkFun_9DoF_ISM330DHCX-MMC5983MA-Panel.GBP, SparkFun_9DoF_ISM330DHCX-MMC5983MA-Panel.GBS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]
2022-06-10 Renames "Qwiic" folder to "Hardware"
    [SparkFun_9DoF_ISM330DHCX-MMC5983MA.brd, SparkFun_9DoF_ISM330DHCX-MMC5983MA.sch]
2022-06-13 Qwiic 9dof TB board update to match design changes
    Design changed to not use sensor hub mode. Changed testbed to reflect those changes
    [SparkFun_9DoF_ISM330DHCX-MMC5983MA.brd]
2022-06-13 Revert "Qwiic 9dof TB board update to match design changes"
    This reverts commit 867b655bef504f495645ea868ae599dd038fac2f.
    [SparkFun_9DoF_ISM330DHCX-MMC5983MA.brd]

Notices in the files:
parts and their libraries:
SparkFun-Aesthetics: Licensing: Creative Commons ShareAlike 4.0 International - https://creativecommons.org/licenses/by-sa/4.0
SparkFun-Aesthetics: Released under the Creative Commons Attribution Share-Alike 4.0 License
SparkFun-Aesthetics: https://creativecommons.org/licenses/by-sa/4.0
